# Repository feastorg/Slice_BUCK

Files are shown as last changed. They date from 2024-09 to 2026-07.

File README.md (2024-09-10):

# Buck Converter / Analog Signal Generator Slice

Buck Converter / Analog Signal Generator Slice for BREAD.

## Introduction

[Short introduction on the project.]

## Usage

[Explain how to use the project. Include examples and screenshots if applicable.]

## Documentation

Please refer to the [docs](/docs) for more info.

---

<div align="center">
  <p>
    
    
  </p>
</div>

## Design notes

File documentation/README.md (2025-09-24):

# Docs

This directory contains the documentation for the project.

## Parts Dump

- **Buck Inductor**  
  [Bourns 1130-561K-RC (Mouser)](https://www.mouser.ca/ProductDetail/Bourns/1130-561K-RC?qs=VY5%2FUM8ph%2FMBak%2F%2FXWqo%2FA%3D%3D)

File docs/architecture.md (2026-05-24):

---
title: "Architecture"
description: "Hardware and firmware architecture overview."
---

# Architecture

## Hardware

Buck converter (step-down DC-DC) power supply slice.

## Firmware

Arduino-based control sketch (`slice_buck.ino`).

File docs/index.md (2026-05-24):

---
title: "Slice BUCK Documentation"
description: "Overview and entry page for Slice BUCK project documentation."
nav_exclude: true
---

Welcome to the Slice BUCK project documentation.

## Board Renders

<figure style="display:inline-block; text-align:center; margin:10px;">
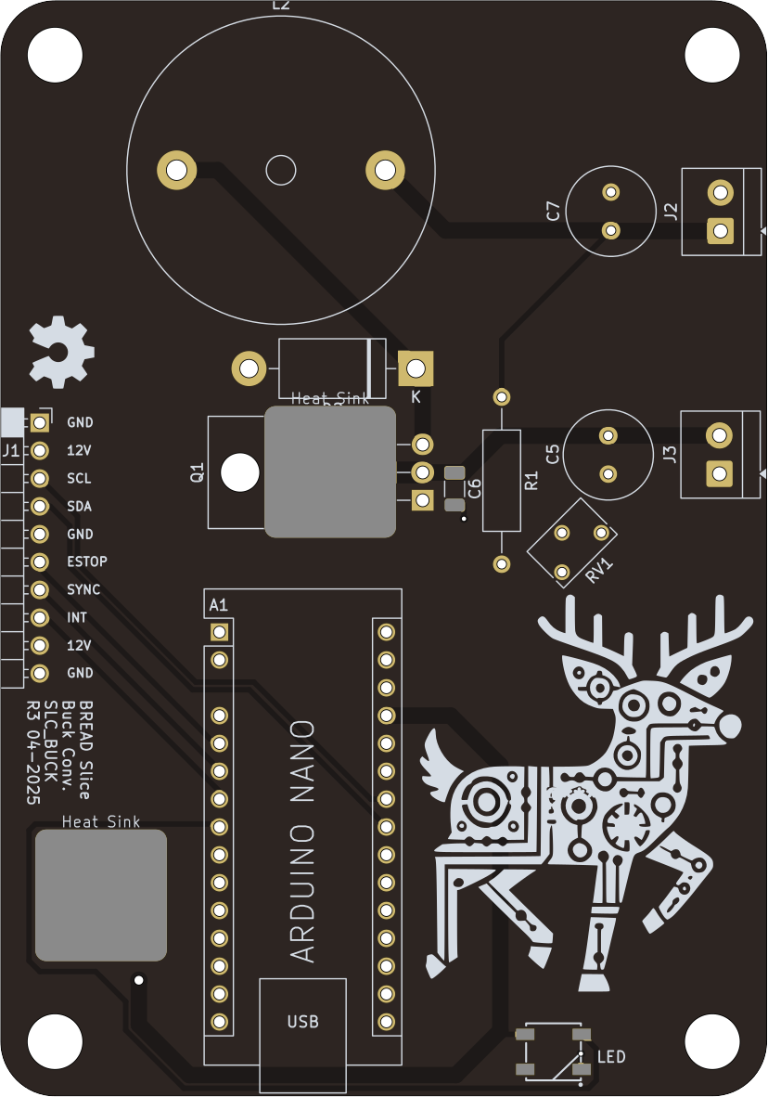
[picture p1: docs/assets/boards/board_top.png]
Board Top
  
  <figcaption>Top</figcaption>
</figure>

<figure style="display:inline-block; text-align:center; margin:10px;">
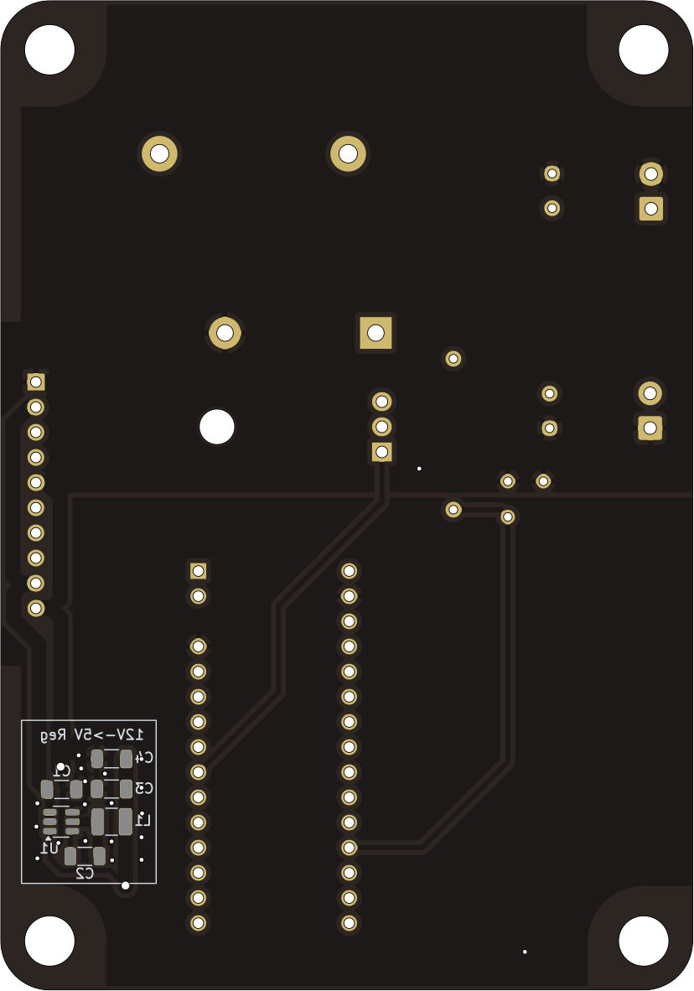
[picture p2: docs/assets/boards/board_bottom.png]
Board Bottom
  
  <figcaption>Bottom</figcaption>
</figure>

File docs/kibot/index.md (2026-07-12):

---
title: "KiBot Outputs"
description: "Index for KiBot-generated PCB artifacts."
layout: "page"
---

These are the docs & KiBot Outputs for Slice BUCK

The following files were generated from the latest PCB build:

- [Schematic.pdf](./Schematic.pdf)
- [PCB.pdf](./PCB.pdf)
- [kibot.log](./kibot.log)
- [BREAD_Slice-bom.html](./BREAD_Slice-bom.html)
- [BREAD_Slice-ibom.html](./BREAD_Slice-ibom.html)

_Last updated automatically on 2026-07-12 at 03:58:42 UTC by KiBot via GitHub Actions._

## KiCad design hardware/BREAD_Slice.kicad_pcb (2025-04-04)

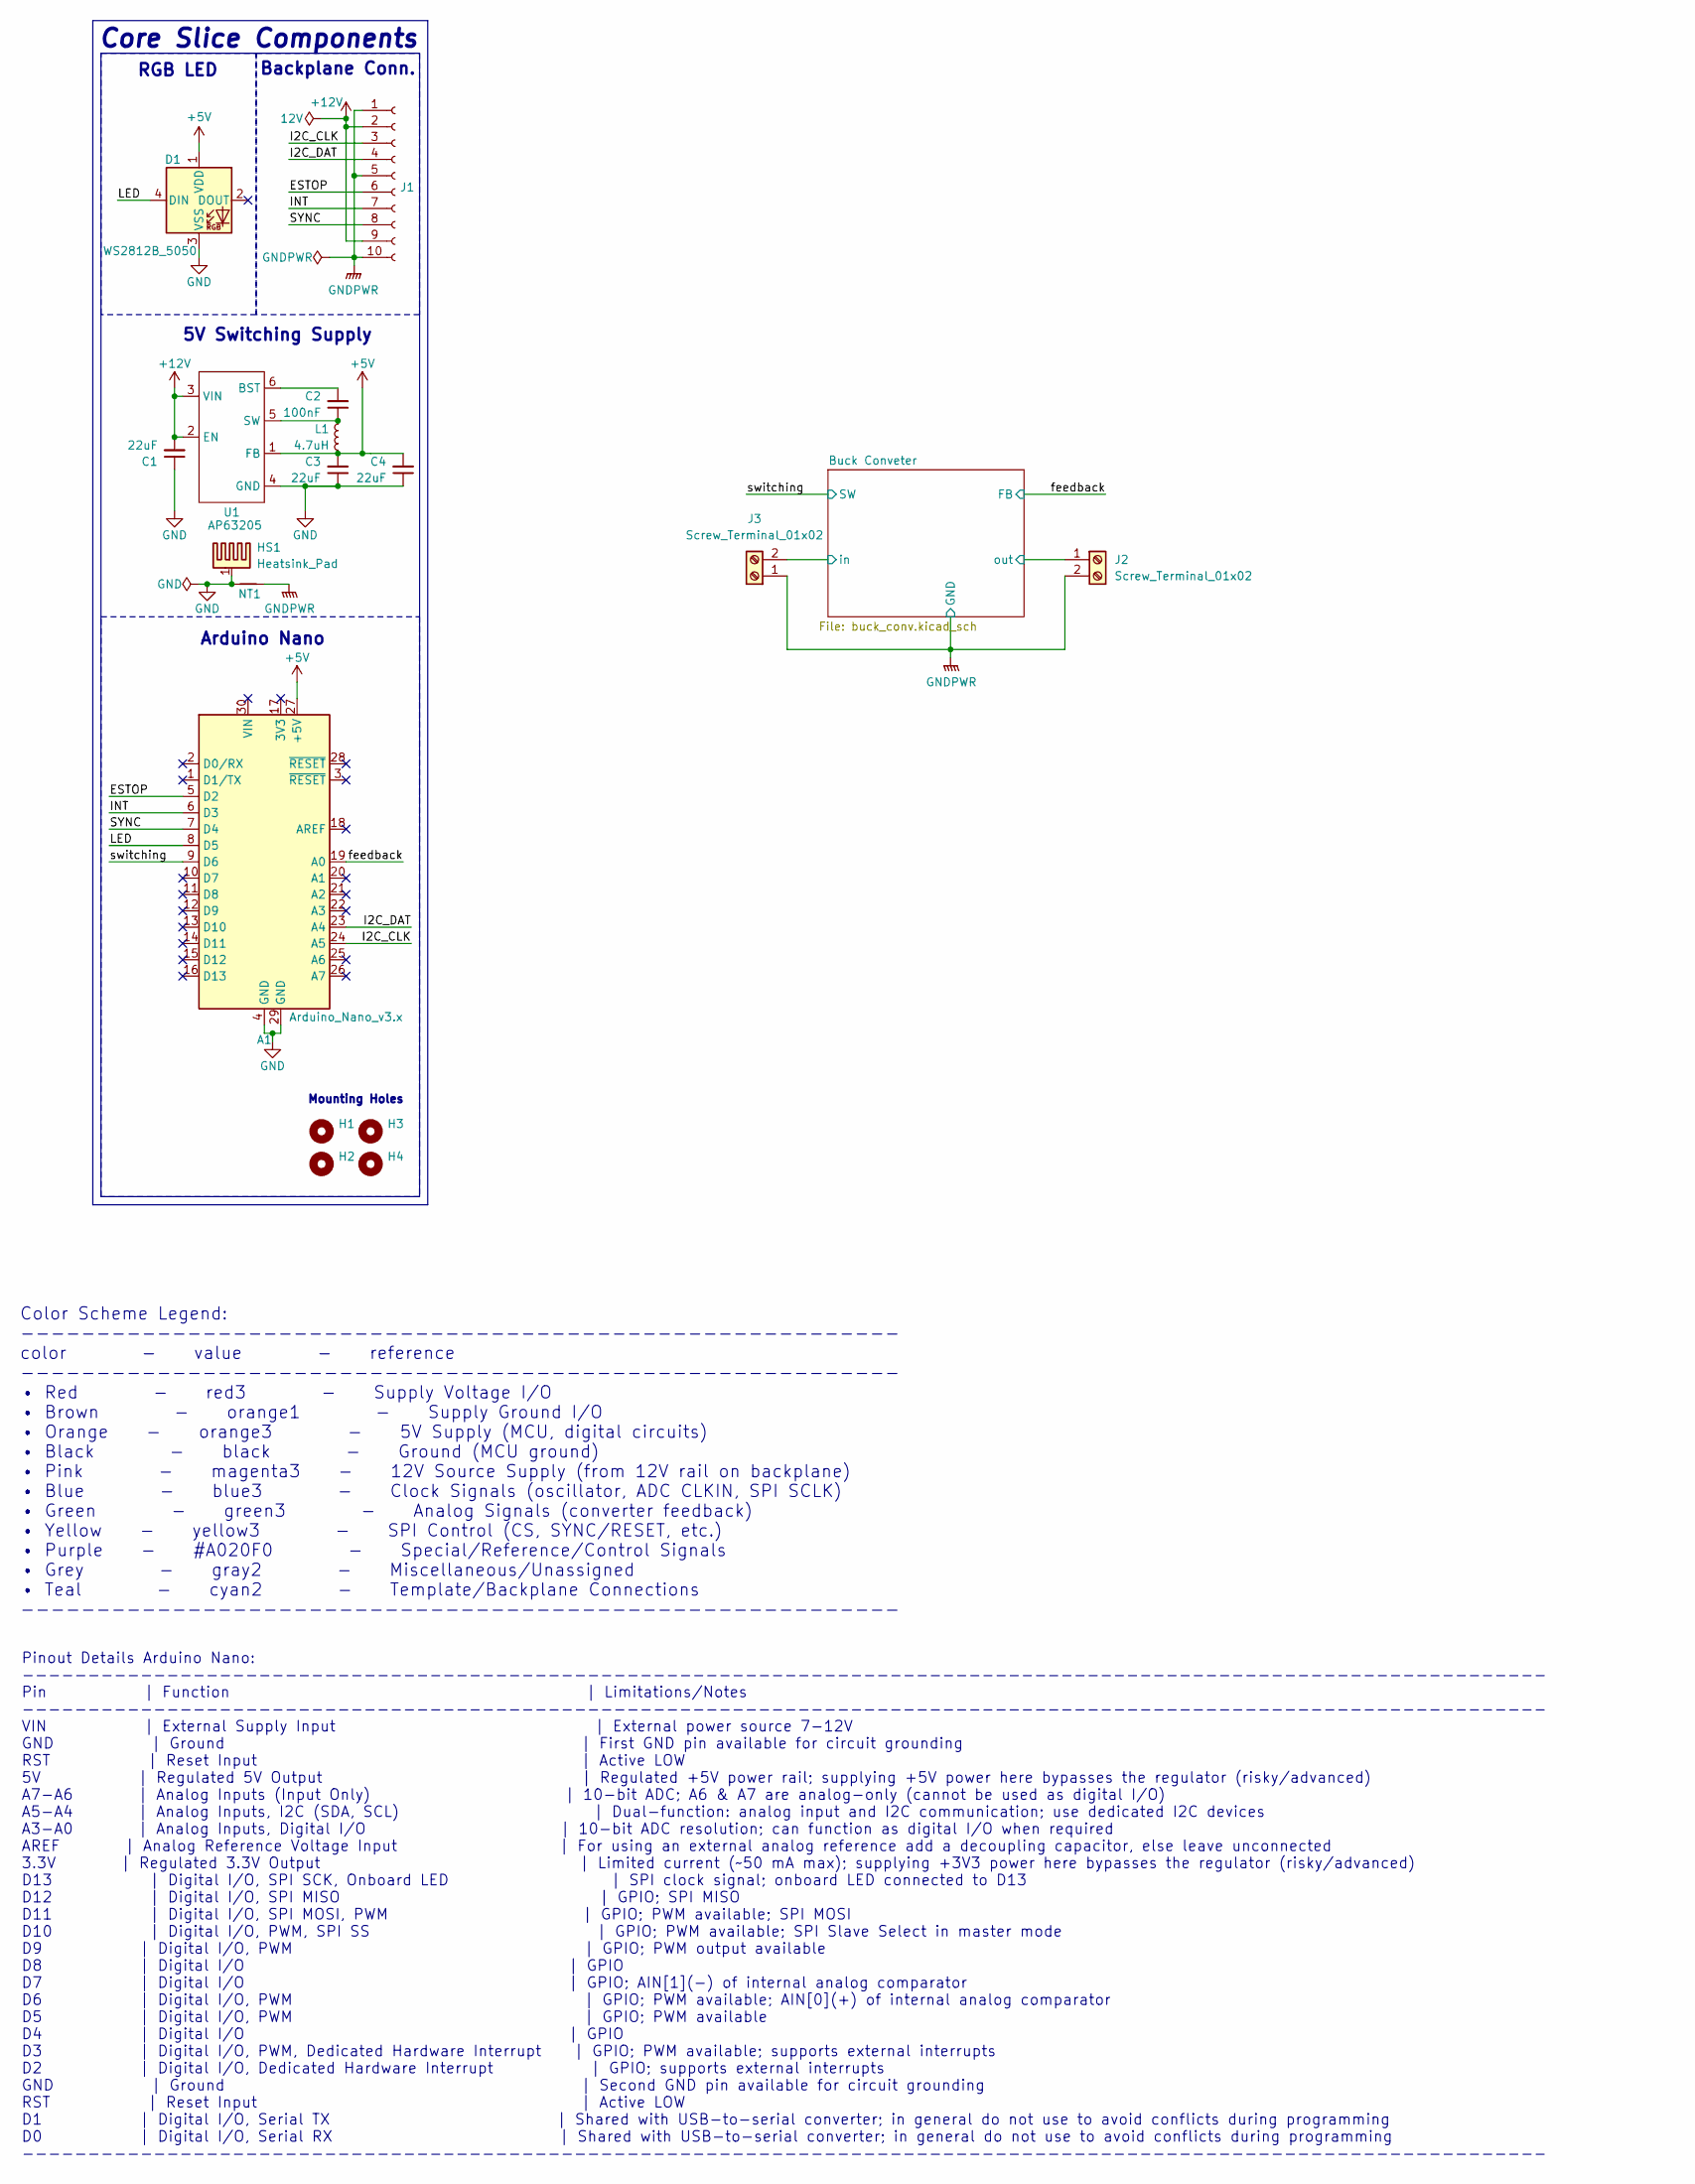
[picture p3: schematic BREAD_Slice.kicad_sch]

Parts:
A1: Arduino_Nano_v3.x; Arduino_Nano
C1, C3, C4: 22uF; C_1206_3216Metric
C2: 100nF; C_1206_3216Metric
D1: WS2812B_5050; WS2812-5050-4PIN
H1, H2, H3, H4: MountingHole; MountingHole_5mm
HS1: Heatsink_Pad; Thermal Pad
J1: Conn_01x10_Female; PinSocket_1x10_P2.54mm_Horizontal
J2, J3: Screw_Terminal_01x02; TerminalBlock_4Ucon_1x02_P3.50mm_Horizontal
L1: 4.7uH; L_1210_3225Metric
NT1: NetTie_2; NetTie-2_SMD_Pad2.0mm
U1: AP63205; TSOT-23-6

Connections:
+5V: A1.27 (+5V), C3.2, C4.2, D1.1 (VDD), L1.2, U1.1 (FB)
+12V: C1.2, J1.2, J1.9, U1.2 (EN), U1.3 (VIN)
/Buck Conveter/in: J3.2; also elsewhere on the board
/Buck Conveter/out: J2.1; also elsewhere on the board
/ESTOP: A1.5 (D2), J1.6
/I2C_CLK: A1.24 (A5), J1.3
/I2C_DAT: A1.23 (A4), J1.4
/INT: A1.6 (D3), J1.7
/LED: A1.8 (D5), D1.4 (DIN)
/SYNC: A1.7 (D4), J1.8
/feedback: A1.19 (A0); also elsewhere on the board
/switching: A1.9 (D6); also elsewhere on the board
GND: A1.4 (GND), A1.29 (GND), C1.1, C3.1, C4.1, D1.3 (VSS), HS1.1, NT1.1, U1.4 (GND)
GNDPWR: J1.1, J1.5, J1.10, J2.2, J3.1, NT1.2; also elsewhere on the board
unnamed: C2.2, U1.6 (BST)
unnamed: C2.1, L1.1, U1.5 (SW)

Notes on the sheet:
5V Switching Supply
Pinout Details Arduino Nano: -------------------------------------------------------------------------------------------------------------------- Pin | Function | Limitations/Notes -------------------------------------------------------------------------------------------------------------------- V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
RGB LED
Color Scheme Legend: ---------------------------------------------------------- color - value - reference ---------------------------------------------------------- • Red - red3 - Supply Voltage I/O • Brown - orange1 - Supply Ground I/O • Orange - orange3 - 5V Supply (MCU, digital circuits) • Black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
Core Slice Components
Arduino Nano
Mounting Holes
Backplane Conn.

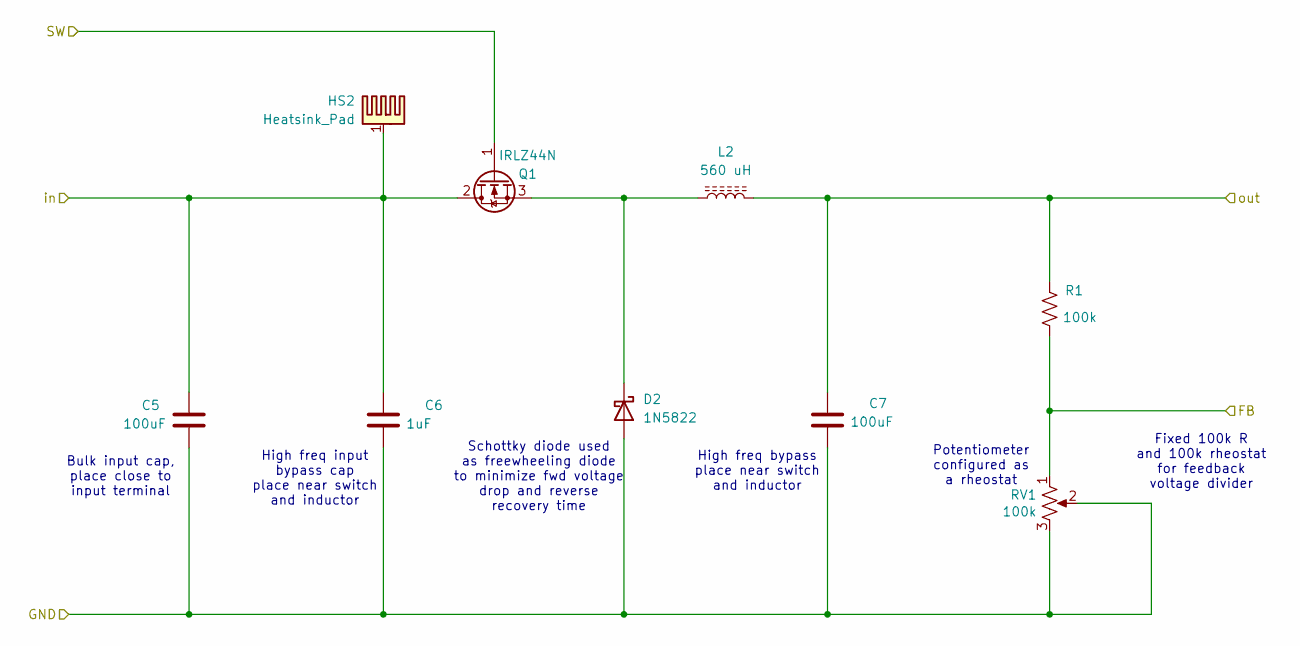
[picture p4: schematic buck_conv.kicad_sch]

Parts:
C5, C7: 100uF; C_Radial_D8.0mm_H11.5mm_P3.50mm
C6: 1uF; C_1206_3216Metric
D2: 1N5822; D_DO-201AD_P15.24mm_Horizontal
HS2: Heatsink_Pad; Thermal Pad
L2: 560 uH; L_Radial_D27.9mm_P19.05mm_Vishay_IHB-3
Q1: IRLZ44N; TO-220-3_Horizontal_TabDown
R1: 100k; R_Axial_DIN0309_L9.0mm_D3.2mm_P15.24mm_Horizontal
RV1: 100k; Potentiometer_Bourns_3266W_Vertical

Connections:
/Buck Conveter/in: C5.1, C6.1, HS2.1, Q1.2 (D); also elsewhere on the board
/Buck Conveter/out: C7.1, L2.2, R1.1; also elsewhere on the board
/feedback: R1.2, RV1.1; also elsewhere on the board
/switching: Q1.1 (G); also elsewhere on the board
GNDPWR: C5.2, C6.2, C7.2, D2.2 (A), RV1.2, RV1.3; also elsewhere on the board
unnamed: D2.1 (K), L2.1, Q1.3 (S)

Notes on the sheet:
Fixed 100k R and 100k rheostat for feedback voltage divider
Schottky diode used as freewheeling diode to minimize fwd voltage drop and reverse recovery time
Bulk input cap, place close to input terminal
High freq bypass place near switch and inductor
High freq input bypass cap place near switch and inductor
Potentiometer configured as a rheostat

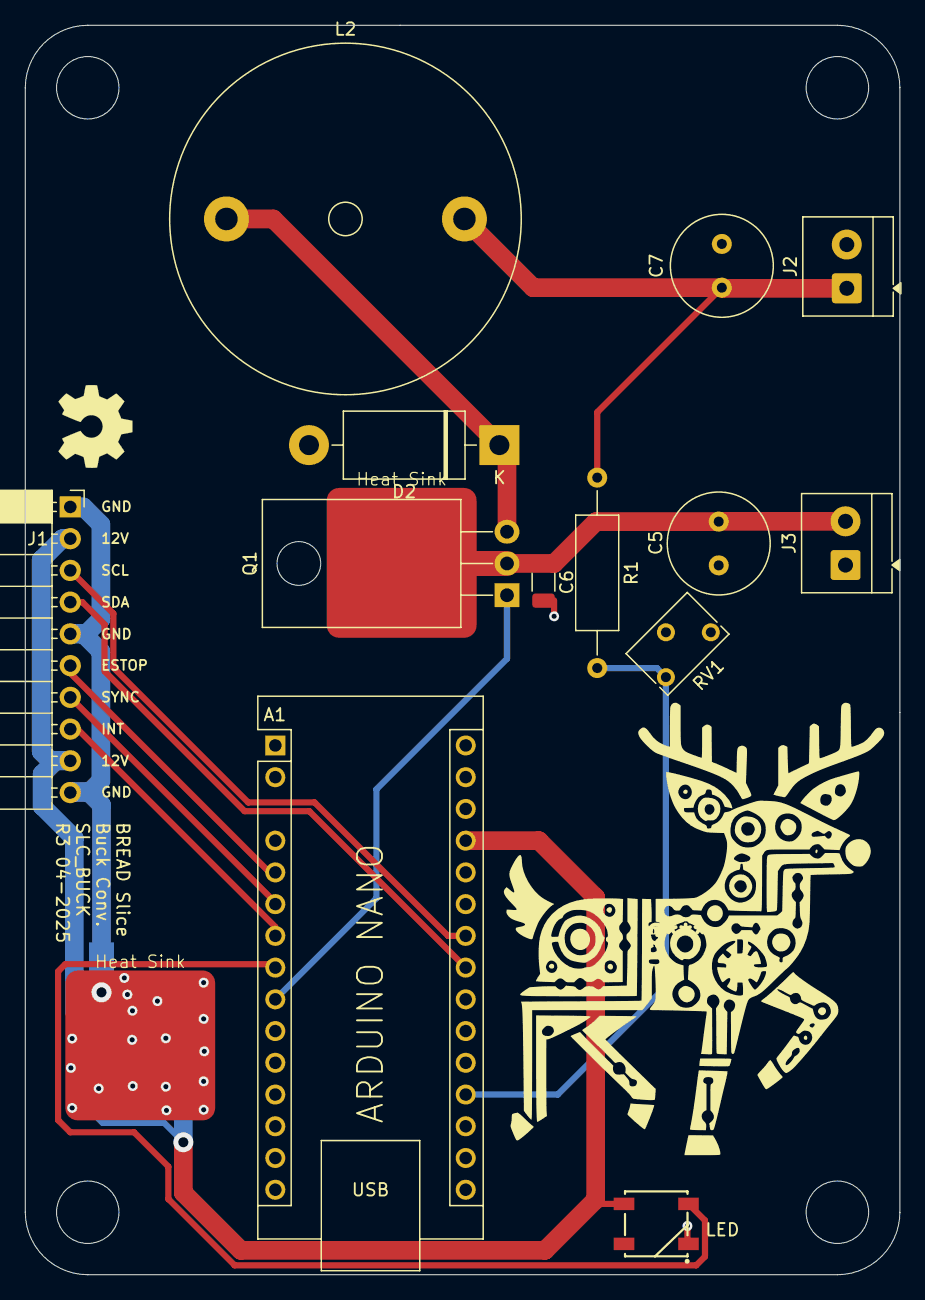
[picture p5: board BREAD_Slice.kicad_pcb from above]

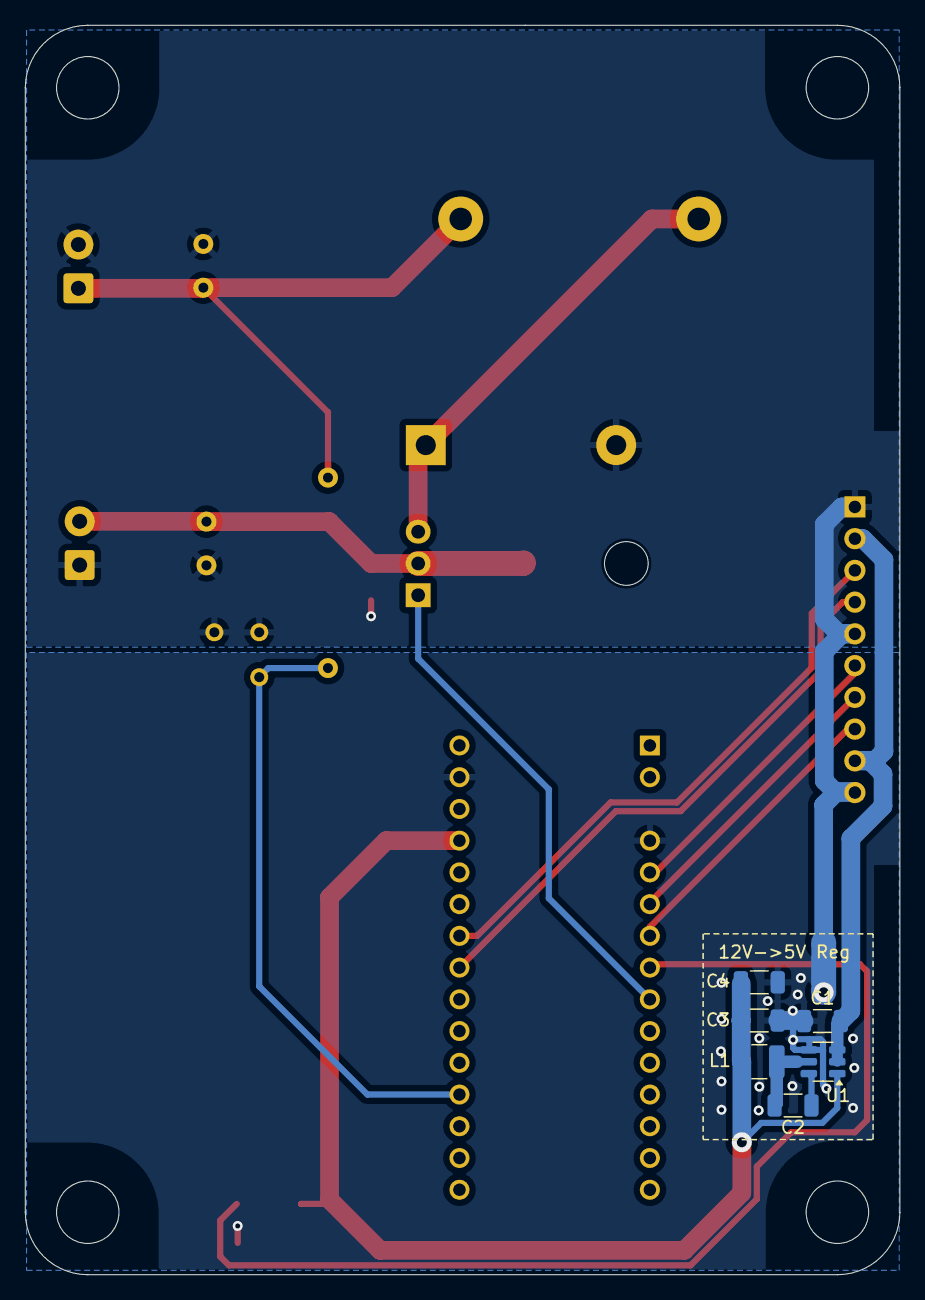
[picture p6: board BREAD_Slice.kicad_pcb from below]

Board: 2 copper layers, 70.0 x 100.0 mm, 27 parts (7 on the bottom side), 17 nets.

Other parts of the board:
Logo1: Logo_Open_Hardware_Small; OSHW-Symbol_6.7x6mm_SilkScreen

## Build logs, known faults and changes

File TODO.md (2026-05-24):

# Slice_BUCK TODO

## CI Results (Pass 1)

- [x] DRC: PASS
- [x] ERC: PASS
- [x] Fab (gerbers, BOM, renders): PASS
- [x] gen-kibot-index: PASS
- [x] deploy-pages: PASS

## Pass 2 – Pre-fab Review

- [ ] Verify BOM completeness
- [ ] Confirm board outline and mounting holes
- [ ] Update README.md (still says "Slice Template")

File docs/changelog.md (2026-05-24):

---
title: "Changelog"
description: "Hardware and firmware revision history."
---

# Changelog

## Hardware

### v0.1.0 (initial)
- Initial schematic and PCB layout
- Buck converter sub-circuit

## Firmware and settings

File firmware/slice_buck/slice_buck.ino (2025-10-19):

//============================================================
// Buck Converter Test - TIP120, L=560 uH, FB on A0, PWM on D6
// Non-blocking status prints; serial control
//============================================================

//---------------- Config & Pins ----------------
const uint8_t PIN_FB  = A0;     // feedback node
const uint8_t PIN_PWM = 6;      // PWM to driver/base (use a base resistor)

// ADC & supply
const float ADC_REF_V   = 5.0f; // Nano default AREF
const int   ADC_MAX     = 1023;

// Divider model (Vout -->[R_TOP]--> FB -->[R_P]--> GND)
float R_TOP_OHM = 98000.0f;    // fixed top resistor (R1)
float R_P_OHM   = 98000.0f;    // effective pot FB->GND; set via SETRP

// PWM
const int PWM_MIN = 0;
const int PWM_MAX = 255;
int pwmDuty = 0;
bool enabled = false;

// Timing
const unsigned long PRINT_MS = 1000;
unsigned long t_lastPrint = 0;

//---------------- Helpers ----------------
float adcToVolts(int raw) {
  return (raw * ADC_REF_V) / ADC_MAX;
}

float estimateVout(float v_fb) {
  // Vout = Vfb * (1 + R_TOP/R_P)
  if (R_P_OHM <= 1.0f) return NAN;
  return v_fb * (1.0f + (R_TOP_OHM / R_P_OHM));
}

void applyPwm() {
  analogWrite(PIN_PWM, enabled ? pwmDuty : 0);
}

void printStatus() {
  int   raw   = analogRead(PIN_FB);
  float v_fb  = adcToVolts(raw);
  float v_out = estimateVout(v_fb);

  Serial.print("STATUS | run:");
  Serial.print(enabled ? "1" : "0");
  Serial.print(" pwm:");
  Serial.print(pwmDuty);
  Serial.print(" raw:");
  Serial.print(raw);
  Serial.print(" v_fb:");
  Serial.print(v_fb, 3);
  Serial.print("V r_top:");
  Serial.print(R_TOP_OHM, 0);
  Serial.print(" r_p:");
  Serial.print(R_P_OHM, 0);
  Serial.print(" est_vout:");
  if (isnan(v_out)) Serial.print("NaN");
  else { Serial.print(v_out, 3); Serial.print("V"); }
  Serial.println();
}

void handleLine(String s) {
  s.trim();
  if (s.length() == 0) return;

  if (s.equalsIgnoreCase("ON")) {
    enabled = true;
    applyPwm();
    Serial.println("OK: ON");
    return;
  }
  if (s.equalsIgnoreCase("OFF")) {
    enabled = false;
    applyPwm();
    Serial.println("OK: OFF");
    return;
  }
  if (s.startsWith("SET ")) {
    int val = s.substring(4).toInt();
    val = constrain(val, PWM_MIN, PWM_MAX);
    pwmDuty = val;
    applyPwm();
    Serial.print("OK: PWM=");
    Serial.println(pwmDuty);
    return;
  }
  if (s.startsWith("SETRP ")) {
    long rp = s.substring(6).toInt();
    if (rp >= 0) {
      R_P_OHM = (float)rp;
      Serial.print("OK: RP=");
      Serial.println((long)R_P_OHM);
    } else Serial.println("ERR: RP");
    return;
  }
  if (s.startsWith("SETTOP ")) {
    long rt = s.substring(7).toInt();
    if (rt > 0) {
      R_TOP_OHM = (float)rt;
      Serial.print("OK: RTOP=");
      Serial.println((long)R_TOP_OHM);
    } else Serial.println("ERR: RTOP");
    return;
  }
  if (s.equalsIgnoreCase("STATUS")) {
    printStatus();
    return;
  }

  Serial.println("CMDS: ON | OFF | SET <0-255> | SETRP <ohm> | SETTOP <ohm> | STATUS");
}

void pollSerial() {
  static String buf;
  while (Serial.available()) {
    char c = (char)Serial.read();
    if (c == '\n' || c == '\r') {
      if (buf.length()) { handleLine(buf); buf = ""; }
    } else {
      if (buf.length() < 80) buf += c; // avoid runaway
    }
  }
}

//---------------- Arduino ----------------
void setup() {
  pinMode(PIN_PWM, OUTPUT);
  analogWrite(PIN_PWM, 0);
  Serial.begin(115200);
  delay(50);
  Serial.println("Buck test ready. CMDS: ON | OFF | SET <0-255> | SETRP <ohm> | SETTOP <ohm> | STATUS");
}

void loop() {
  pollSerial();

  unsigned long now = millis();
  if (now - t_lastPrint >= PRINT_MS) {
    t_lastPrint = now;
    printStatus();
  }
}

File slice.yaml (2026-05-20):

schema_version: "1.0"

# ── Identity ──────────────────────────────────────────────────────────────────
id: "slice-buck"
name: "Buck Converter / Analog Signal Generator"
status: "concept"
category: "power"

summary: "Programmable buck converter slice for variable DC output voltage."
description: null

# ── Versioning ────────────────────────────────────────────────────────────────
version:
  hardware: "0.1.0"
  firmware: "0.1.0"
  manifest: "0.1.0"

# ── Compatibility ─────────────────────────────────────────────────────────────
compatibility:
  slice_spec: ">=0.1.0 <0.2.0"
  crumbs_protocol: null
  anolis_provider_api: null

# ── Hardware ──────────────────────────────────────────────────────────────────
hardware:
  mcu:
    type: "dev-board-socket"
    form_factor: "nano"
    primary: "ATmega328P"
    supported:
      - "ATmega328P"
  primary_ic: null
  hw_gen_current: 1
  hw_gen_supported: [1]
  pcb:
    layers: 2
    thickness: "1.6mm"
    copper_weight: "1oz"
    dimensions: "70mm x 100mm"
  connectors:
    - ref: "J1"
      type: "slice-bus-10pin"
      purpose: "power-and-i2c"
  mounting:
    pattern: "slice-standard-v0"
    hole_size: "M3"
    inset: "5mm"
  pcb_color_prototype: null
  pcb_color_production: null
  enclosure:
    supported: false
    path: null

# ── Electrical ────────────────────────────────────────────────────────────────
electrical:
  input_voltage: "12V"
  logic_voltage: "5V"
  max_current: null
  protection: null
  isolation: null

# ── Interfaces ────────────────────────────────────────────────────────────────
interfaces:
  host:
    type: "i2c"
    address_default: null
    address_configurable: false
  data:
    inputs:
      - name: "FB"
        type: "analog-voltage-divider"
    outputs:
      - name: "VOUT"
        type: "pwm-buck"

# ── Capabilities ──────────────────────────────────────────────────────────────
capabilities:
  - id: "dc_voltage_output"
    channels: 1
    control_modes: ["open_loop"]

# ── Firmware ──────────────────────────────────────────────────────────────────
firmware:
  required: true
  path: "firmware/"
  language: "c++"
  framework: "arduino"
  targets:
    - "nano"
  lib_deps: []

# ── Protocol ──────────────────────────────────────────────────────────────────
protocol:
  type: "serial"
  discovery:
    supported: false
  commands: []

# ── Software ──────────────────────────────────────────────────────────────────
software: null

# ── Artifacts ─────────────────────────────────────────────────────────────────
artifacts:
  schematic: "hardware/BREAD_Slice.kicad_sch"
  pcb: "hardware/BREAD_Slice.kicad_pcb"
  firmware: "firmware/"
  docs: null
  bom: "documentation/BOM_TEMP.ods"
  gerbers: null
  pick_and_place: null
  datasheets: []

# ── Manufacturing ─────────────────────────────────────────────────────────────
manufacturing: null

# ── Validation ────────────────────────────────────────────────────────────────
validation: null

# ── Safety ────────────────────────────────────────────────────────────────────
safety: null

# ── Dependencies ──────────────────────────────────────────────────────────────
dependencies: null

# ── Relations ─────────────────────────────────────────────────────────────────
related: null

# ── Maintainers ───────────────────────────────────────────────────────────────
maintainers:
  - name: "Cameron Brooks"
    role: "owner"

# ── License ───────────────────────────────────────────────────────────────────
license:
  hardware: "CERN-OHL-S-2.0"
  firmware: "GPL-3.0-or-later"
  software: null
  docs: "CC-BY-4.0"

# ── Repository ────────────────────────────────────────────────────────────────
repository:
  url: "https://github.com/feastorg/Slice_BUCK"

# ── Metadata ──────────────────────────────────────────────────────────────────
metadata:
  created: "2026-05-19"
  updated: "2026-05-19"
  tags:
    - "power"
    - "buck-converter"
    - "dc-dc"
    - "signal-generator"

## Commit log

2024-08-16 updated to new BREAD format
    [BREAD_Slice-B_Cu.gbr, BREAD_Slice-B_Mask.gbr, BREAD_Slice-B_Paste.gbr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]
2024-08-16 removed legacy hardware
    [BREAD_Slice-B_Cu.gbr, BREAD_Slice-B_Mask.gbr, BREAD_Slice-B_Paste.gbr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]
2024-08-30 updated outputs for fab
    [BREAD_Slice-B_Cu.gbr, BREAD_Slice-B_Mask.gbr, BREAD_Slice-B_Paste.gbr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]
2024-08-30 minor updates
    [BREAD_Slice-B_Cu.gbr, BREAD_Slice-B_Mask.gbr, BREAD_Slice-B_Paste.gbr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]
2024-09-27 cleaned up erc & drc
    [BREAD_Slice-B_Cu.gbr, BREAD_Slice-B_Mask.gbr, BREAD_Slice-B_Paste.gbr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]
2024-09-30 JLCPCB order rev-A
    [BREAD_Slice-B_Cu.gbr, BREAD_Slice-B_Mask.gbr, BREAD_Slice-B_Paste.gbr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]
2025-03-31 updated to use latest template
    [BREAD_Slice-B_Cu.gbr, BREAD_Slice-B_Mask.gbr, BREAD_Slice-B_Paste.gbr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]
2025-03-31 removed old
    [BREAD_Slice-B_Cu.gbr, BREAD_Slice-B_Mask.gbr, BREAD_Slice-B_Paste.gbr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]
2025-03-31 removed i2c conn silk
    [BREAD_Slice.kicad_pcb]
2025-04-04 finalized to 2L templ
    [BREAD_Slice.kicad_pcb, BREAD_Slice.kicad_sch, buck_conv.kicad_sch]
2025-10-19 add attempt script to use current buck
2026-05-24 📄 KiBot index + board renders (auto)
